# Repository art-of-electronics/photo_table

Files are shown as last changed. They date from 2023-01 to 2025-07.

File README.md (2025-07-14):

# Photo table

<div align="center">
  
</div>

Folders contain following files:
1) CAD: table step and stl files for NEMA17 and NEMA23 type stepper motors, 
2) GERB: gerber files for production (upload to JLCPCB and have fun), 
3) Kicad: Kicad 6 project files, so you can fiddle to your hert's content.

I have also uploaded a schematic in pdf file and sample code in micropython for Wemos D1 mini (ESP8266) and Wemos S2 (ESP32) boards in main folder. 

**Tripple check GPIOs on your version of ESP before uploading the code!**

---

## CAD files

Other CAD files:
CAD/table_nema17.stl
CAD/table_nema23.stl

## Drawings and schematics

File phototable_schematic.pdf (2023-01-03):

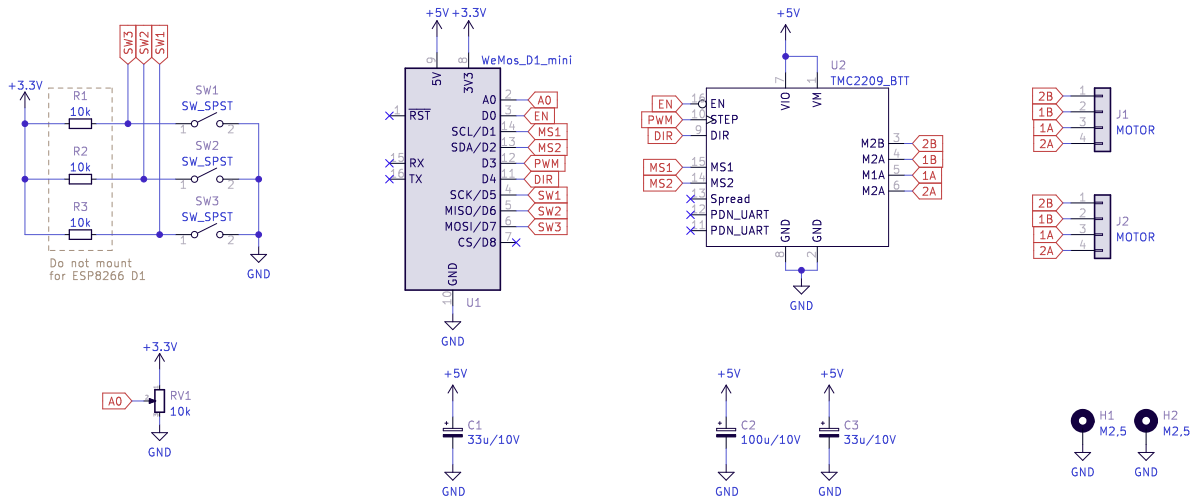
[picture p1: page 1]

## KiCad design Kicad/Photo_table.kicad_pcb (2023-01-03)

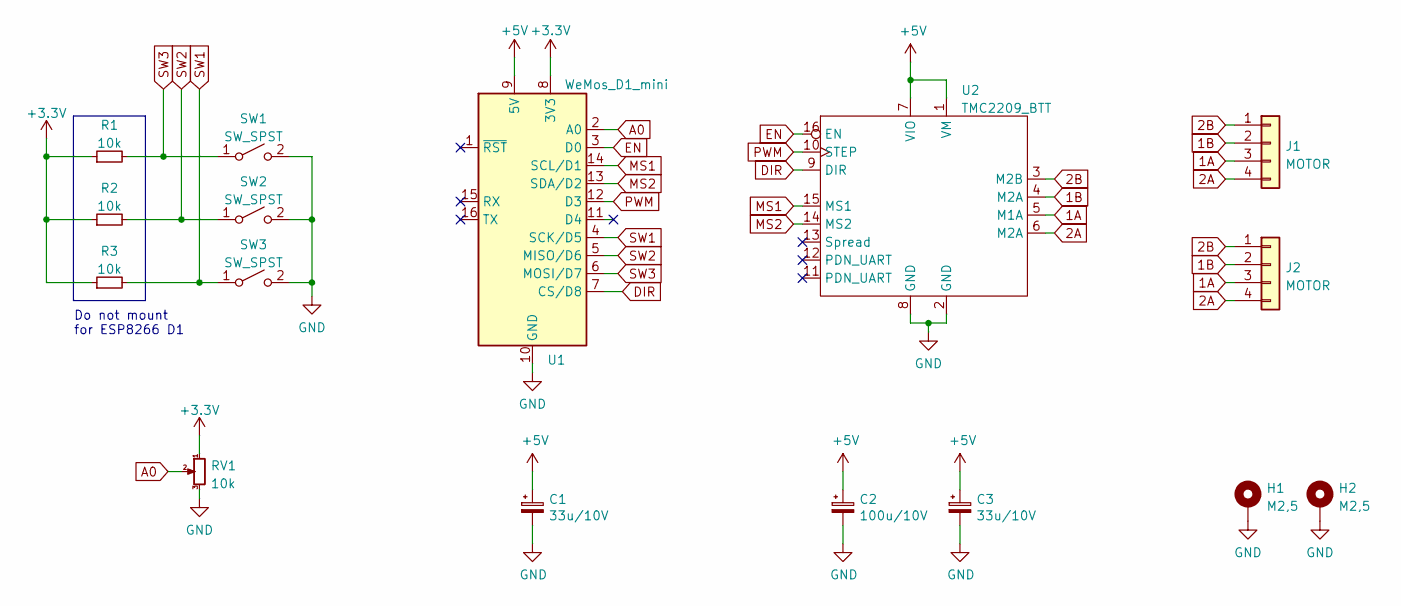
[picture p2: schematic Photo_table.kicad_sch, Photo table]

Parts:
C1, C3: 33u/10V; C_Elec_5x5.4
C2: 100u/10V; C_Elec_8x6.2
H1, H2: M2,5; MountingHole_2.5mm_Pad_Via
J1: MOTOR; PinHeader_1x04_P2.54mm_Vertical
J2: MOTOR; TLZ24V-5.0-4
R1, R2, R3: 10k; R_1206_3216Metric
RV1: 10k; POT9x11
SW1, SW2, SW3: SW_SPST; SW_PUSH_6mm
U1: WeMos_D1_mini; WEMOS_D1_mini_light
U2: TMC2209_BTT; TMC2209_THT

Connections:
1A: J1.3, J2.3, U2.5 (M1A)
1B: J1.2, J2.2, U2.4 (M2A)
2A: J1.4, J2.4, U2.6 (M2A)
2B: J1.1, J2.1, U2.3 (M2B)
+3V3: R1.1, R2.1, R3.1, RV1.1, U1.8 (3V3)
+5V: C1.1, C2.1, C3.1, U1.9 (5V), U2.1 (VM), U2.7 (VIO)
A0: RV1.2, U1.2 (A0)
DIR: U1.7 (CS/D8), U2.9 (DIR)
EN: U1.3 (D0), U2.16 (EN)
GND: C1.2, C2.2, C3.2, H1.1, H2.1, RV1.3, SW1.2 (B), SW2.2 (B), SW3.2 (B), U1.10 (GND), U2.2 (GND), U2.8 (GND)
MS1: U1.14 (SCL/D1), U2.15 (MS1)
MS2: U1.13 (SDA/D2), U2.14 (MS2)
PWM: U1.12 (D3), U2.10 (STEP)
SW1: R3.2, SW3.1 (A), U1.4 (SCK/D5)
SW2: R2.2, SW2.1 (A), U1.5 (MISO/D6)
SW3: R1.2, SW1.1 (A), U1.6 (MOSI/D7)

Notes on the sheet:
Do not mount for ESP8266 D1

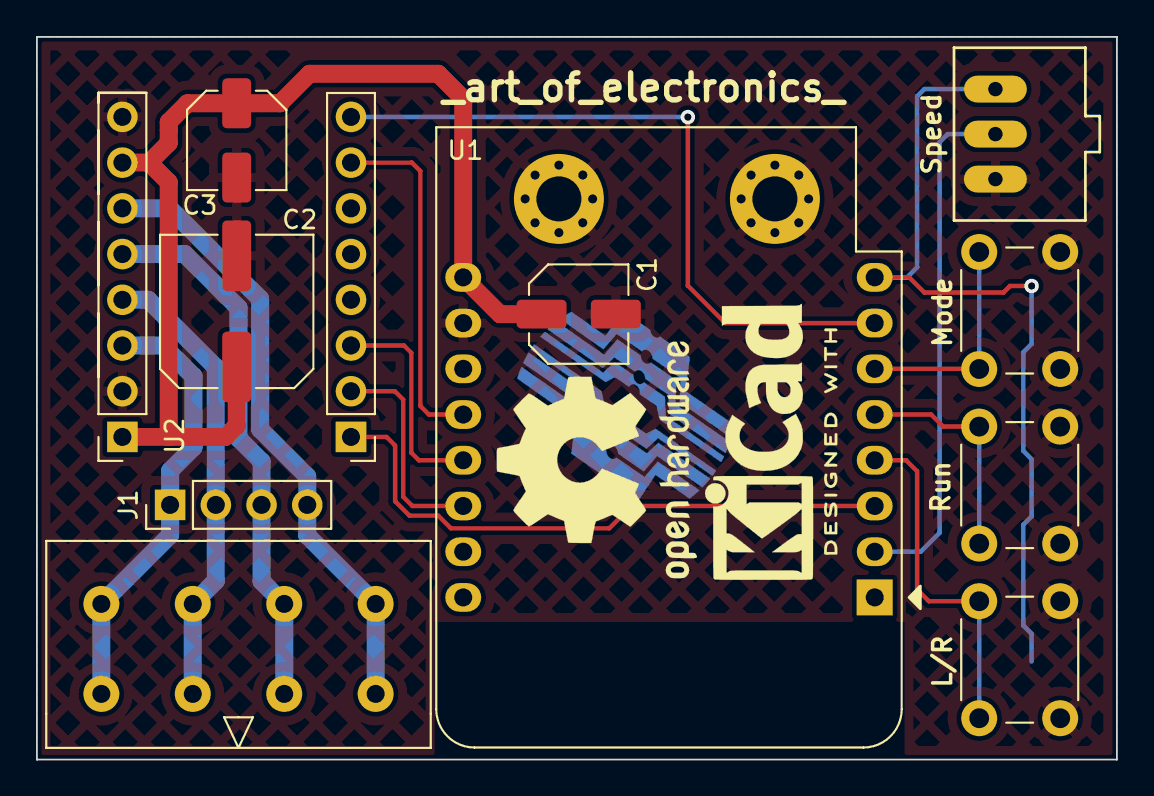
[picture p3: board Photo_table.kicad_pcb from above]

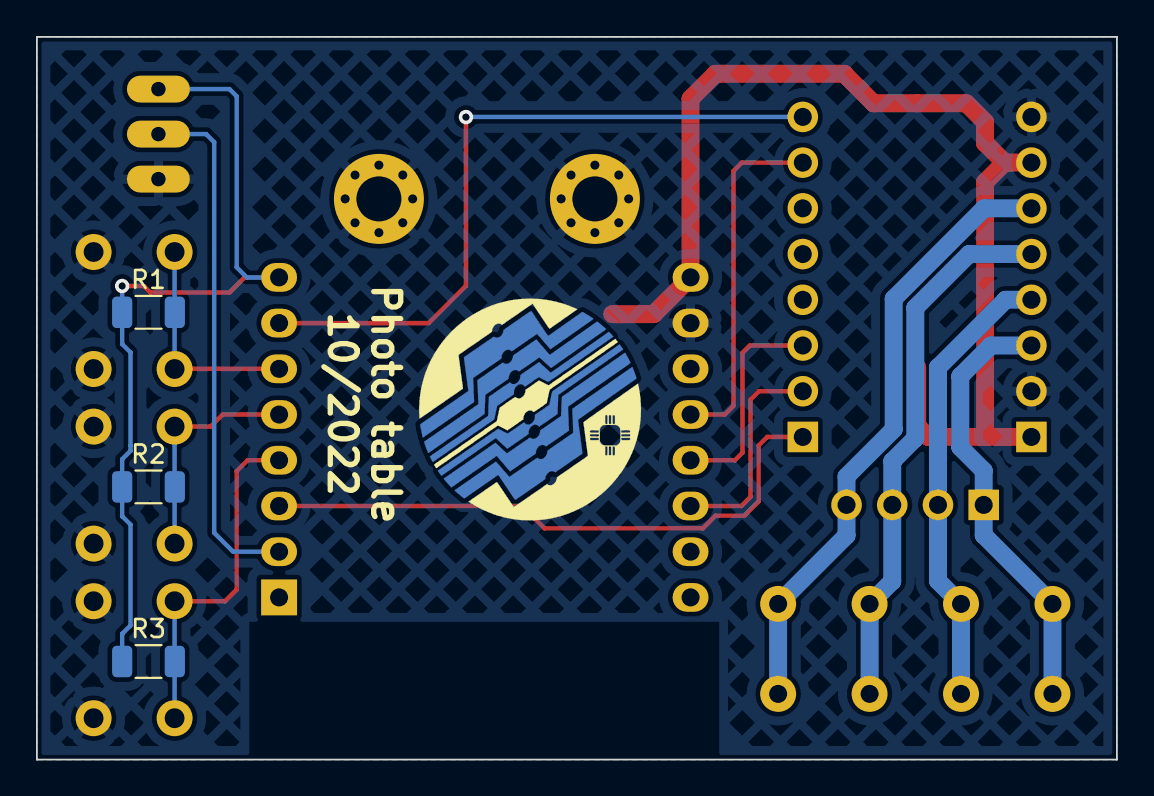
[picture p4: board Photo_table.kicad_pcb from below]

Board: 2 copper layers, 60.0 x 40.1 mm, 16 parts (3 on the bottom side), 16 nets.

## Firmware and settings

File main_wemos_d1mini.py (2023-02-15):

from machine import Pin, ADC, PWM
from time import sleep

adc = ADC(0)

led = Pin(2, Pin.OUT)
led.on()

lr_dir = Pin(14, Pin.IN, Pin.PULL_UP)
run = Pin(12, Pin.IN, Pin.PULL_UP)
mode = Pin(13, Pin.IN, Pin.PULL_UP)

en = Pin(16, Pin.OUT)
en.on()
ms1 = Pin(5, Pin.OUT)
ms1.off()
ms2 = Pin(4, Pin.OUT)
ms2.off()
dr = Pin(15, Pin.OUT)
pwm = PWM(Pin(0), duty=0)


class Cnt:
    sw1 = False
    sw2 = False
    sw3 = False
    ms_mode = 0
    f = 1000


last_sw1 = last_sw2 = last_sw3 = 0


def toggle_led():
    led.value(led.value() ^ 1)
    en.value(en.value() ^ 1)
    if en.value() == 0:
        pwm.duty(512)
    else:
        pwm.duty()


def key_dir():
    global last_sw1
    last_sw1 = Cnt.sw1
    Cnt.sw1 = lr_dir.value()
    if last_sw1 and not Cnt.sw1:
        dr.value(dr.value() ^ 1)


def key_run():
    global last_sw2
    last_sw2 = Cnt.sw2
    Cnt.sw2 = run.value()
    if last_sw2 and not Cnt.sw2:
        toggle_led()


def key_mode():
    global last_sw3
    last_sw3 = Cnt.sw3
    Cnt.sw3 = mode.value()
    if last_sw3 and not Cnt.sw3:
        Cnt.ms_mode += 1
        if Cnt.ms_mode == 1:
            ms1.on()
            ms2.on()
        elif Cnt.ms_mode == 2:
            ms1.on()
            ms2.off()
        elif Cnt.ms_mode == 3:
            ms1.off()
            ms2.on()
        else:
            ms1.off()
            ms2.off()
            Cnt.ms_mode = 0


while True:
    f = 500 + ((int(adc.read() / 100)) * 80)
    pwm.freq(f)
    key_dir()
    key_run()
    key_mode()
    sleep(0.01)
